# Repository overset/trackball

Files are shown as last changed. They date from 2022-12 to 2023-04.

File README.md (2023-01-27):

## Trackball Mezzanine PCBs

These are the mezzanine PCBs that connect the <a href="https://www.adafruit.com/product/4600">Adafruit QT Py</a> (SAMD21) MCU, <a href="https://github.com/mrjohnk/PMW3389DM">MrJohnK PMW3389</a> optical sensor breakout (<a href="https://www.tindie.com/products/jkicklighter/pmw3389-motion-sensor/">available on Tindie as of 2022</a>), simple components for the haptic feedback motor and pads for capacitive pickup wiring. This PCB allows for easy mounting inside the case for most components as well as a ground plane to help with the capacitive pickup interference. These are simple 2-layer PCBs that made with KiCad6 and includes a few custom footprints/symbols for the haptic motor. These can easily be fabricated through OSHPark, JLCPCB, etc. Original prototypes were fabricated by OSHPark and the gerber & hole files were exported from KiCad6 with OSHPark guidelines.

### Dual Optical Sensor PCB

*Currently work in progress*

This mezzanine PCB supports 2 optical sensor breakout boards being tested on a new case design. This leverages the PMW3389DM-T3QU or PMW3360DM-T2QU breakout boards from MrJohnK. Having the second optical sensor enables detecting horizontal ball movement (like a flat spin) to enable scroll/wheel events. This is specifically designed to work with the current case design detecting movements off a radial ball bearing for 1 sensor (scroll) and the trackball itself (x, y cursor movement).

<p align="center">
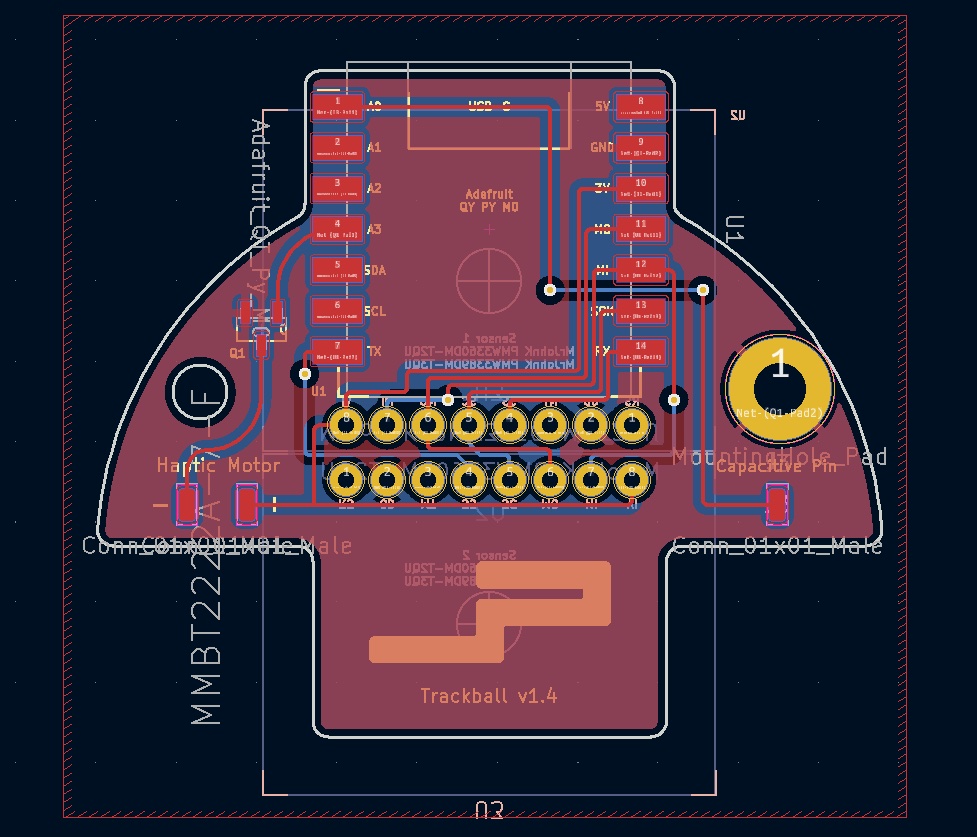
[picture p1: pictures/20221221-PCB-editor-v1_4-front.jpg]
	<span align="left"></span>
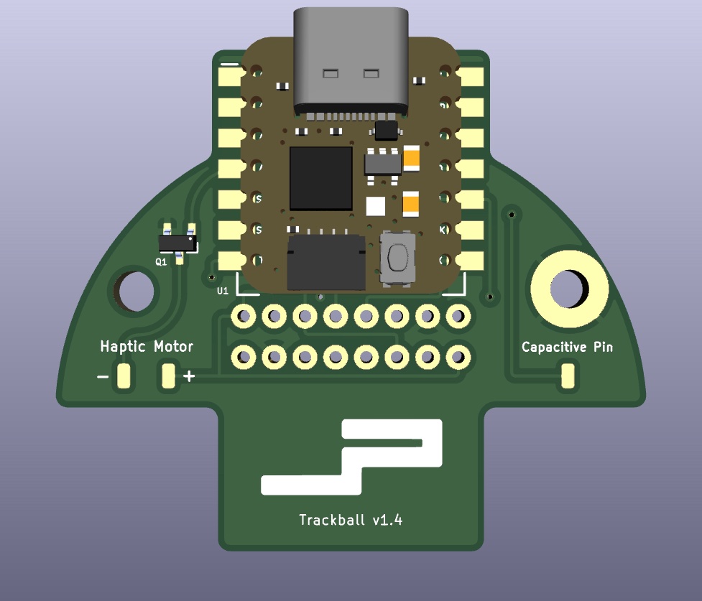
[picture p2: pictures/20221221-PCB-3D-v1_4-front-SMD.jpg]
	<span align="left"></span>
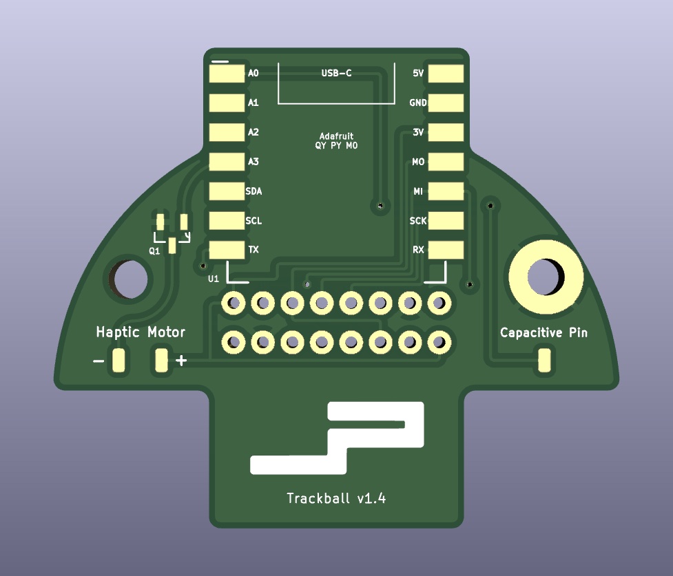
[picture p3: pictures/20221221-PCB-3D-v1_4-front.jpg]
	<span align="left"></span>
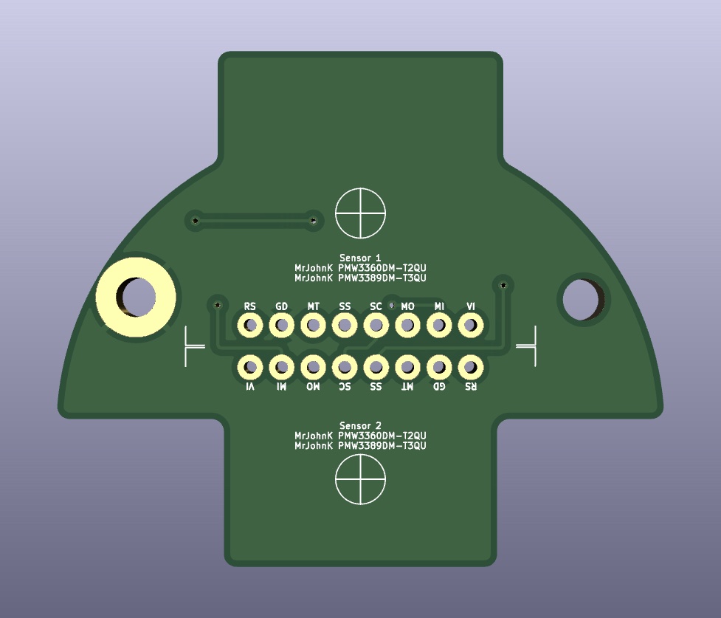
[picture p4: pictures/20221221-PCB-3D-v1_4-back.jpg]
	<span align="right"></span>
</p>

<p align="center">
	
</p>

### Single Optical Sensor PCB

This mezzanine PCB supports a single optical sensor breakout and is good for a dedicated trackball or dedicated scrollball. This allows for a smaller case design, but made with using a 50mm or larger ball.

<p align="center">
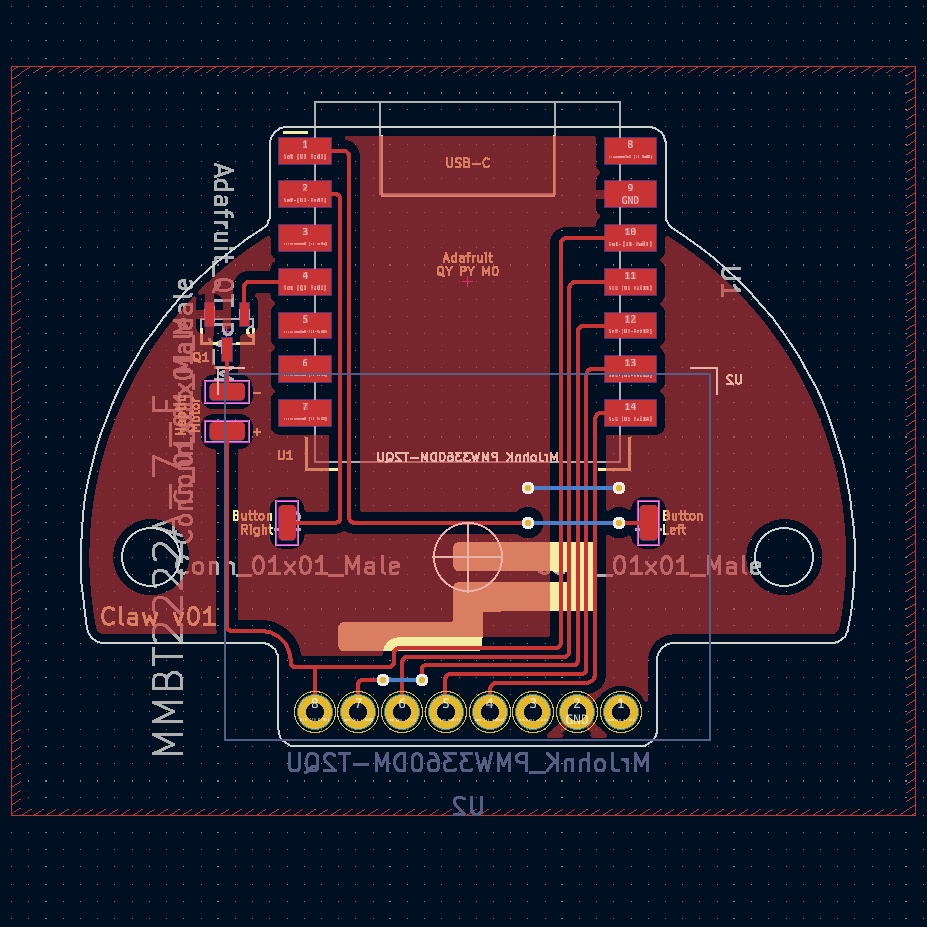
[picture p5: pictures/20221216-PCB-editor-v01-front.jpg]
	<span align="left"></span>
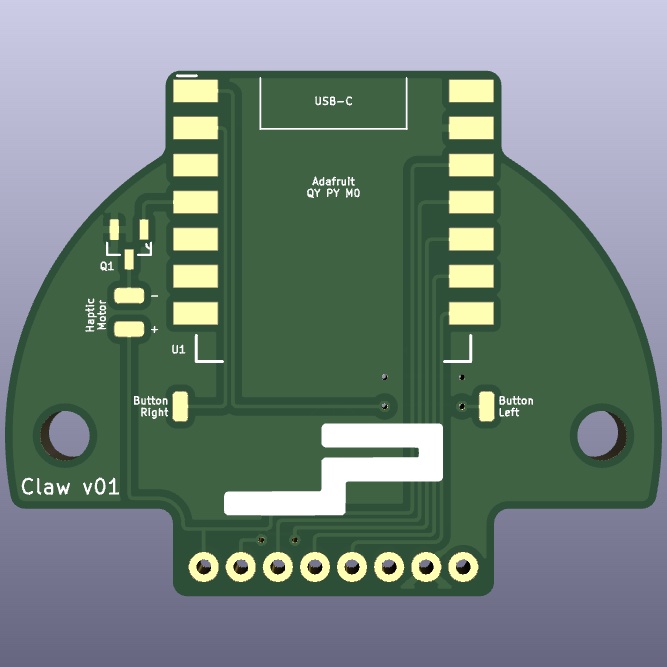
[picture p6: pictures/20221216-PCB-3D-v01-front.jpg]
	<span align="left"></span>
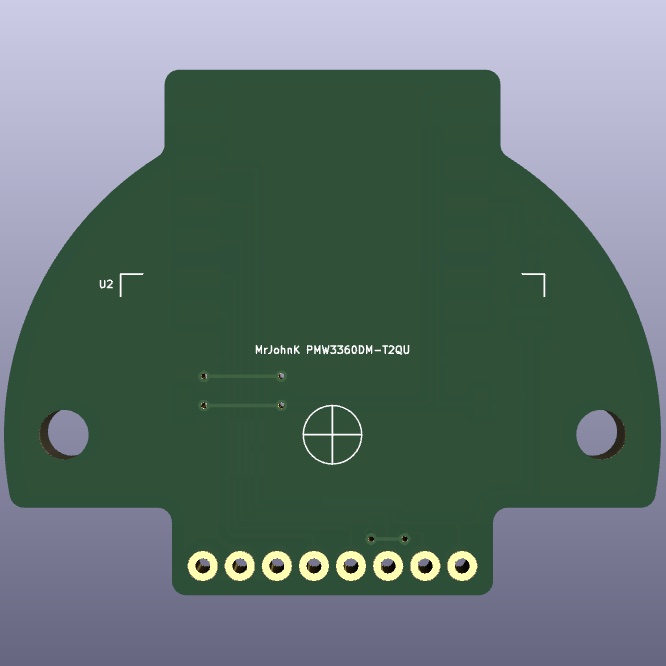
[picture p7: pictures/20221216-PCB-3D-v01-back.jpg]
	<span align="right"></span>
</p>

Assembly of the first print:

<p align="center">
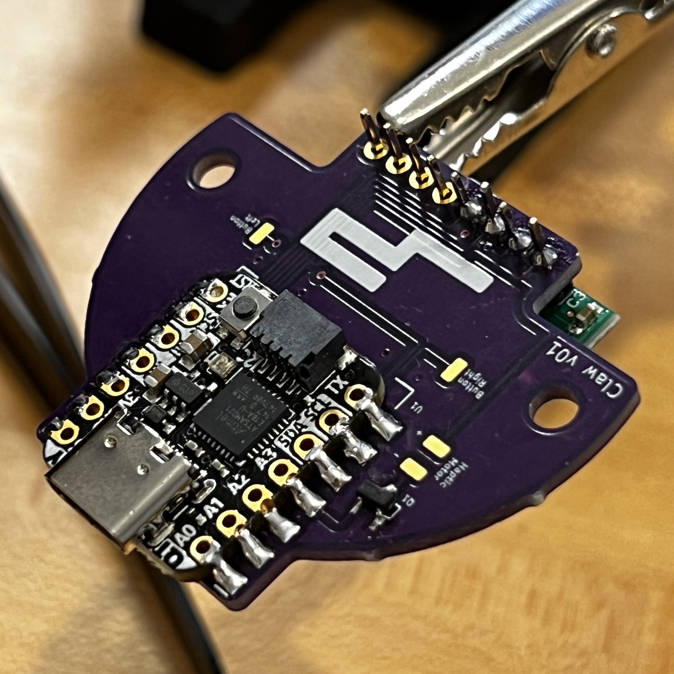
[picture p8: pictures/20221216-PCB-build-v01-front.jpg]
	<span align="left"></span>
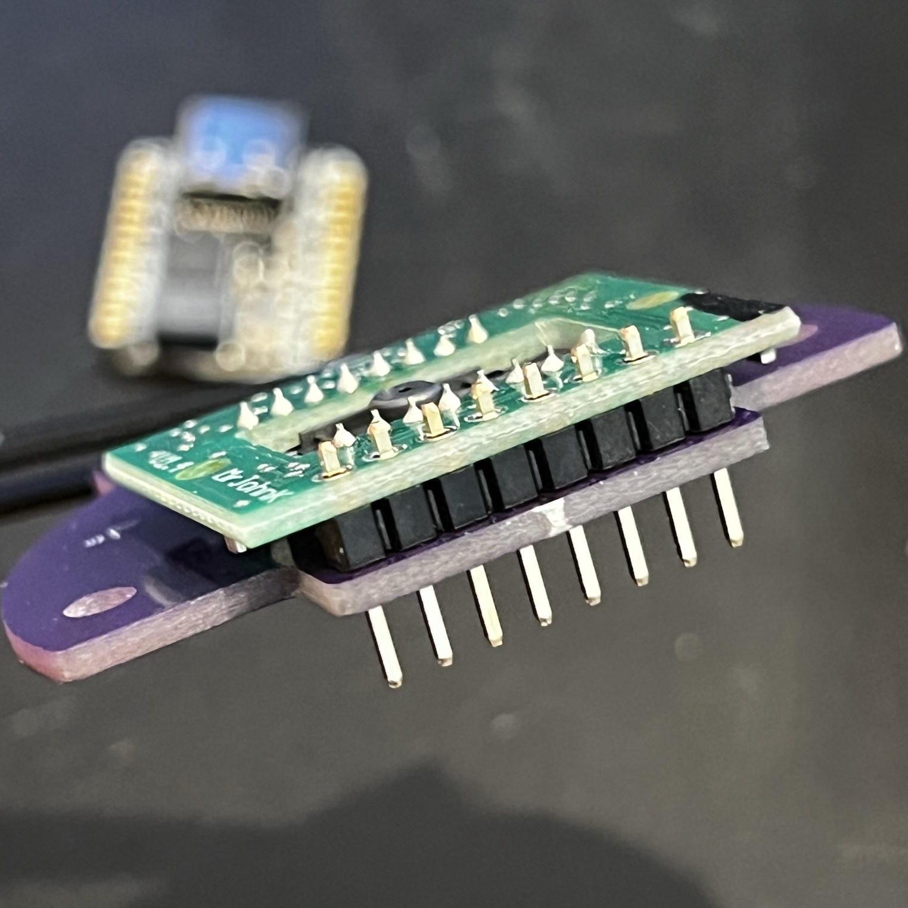
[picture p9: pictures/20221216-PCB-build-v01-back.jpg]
	<span align="left"></span>
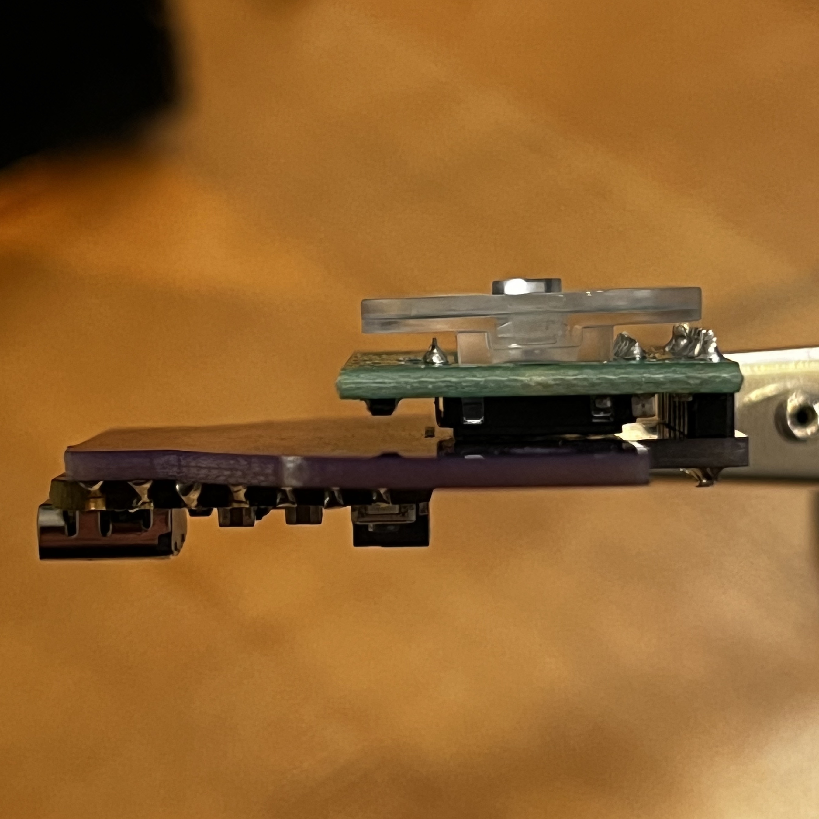
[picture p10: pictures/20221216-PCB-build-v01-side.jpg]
	<span align="right"></span>
</p>

## Credits, Attribution and Inspiration

* <a href="https://github.com/monroewilliams/trackball">MonroeWilliams' Trackball</a> project
* <a href="https://github.com/jfedor2">jfedor2's multiple trackball</a> projects

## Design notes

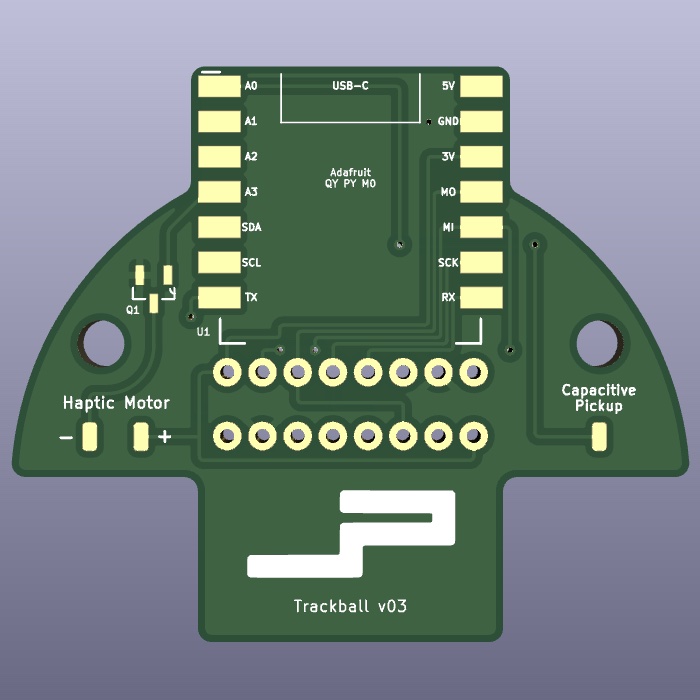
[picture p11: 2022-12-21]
pictures/20221221-PCB-3D-v03-front.jpg

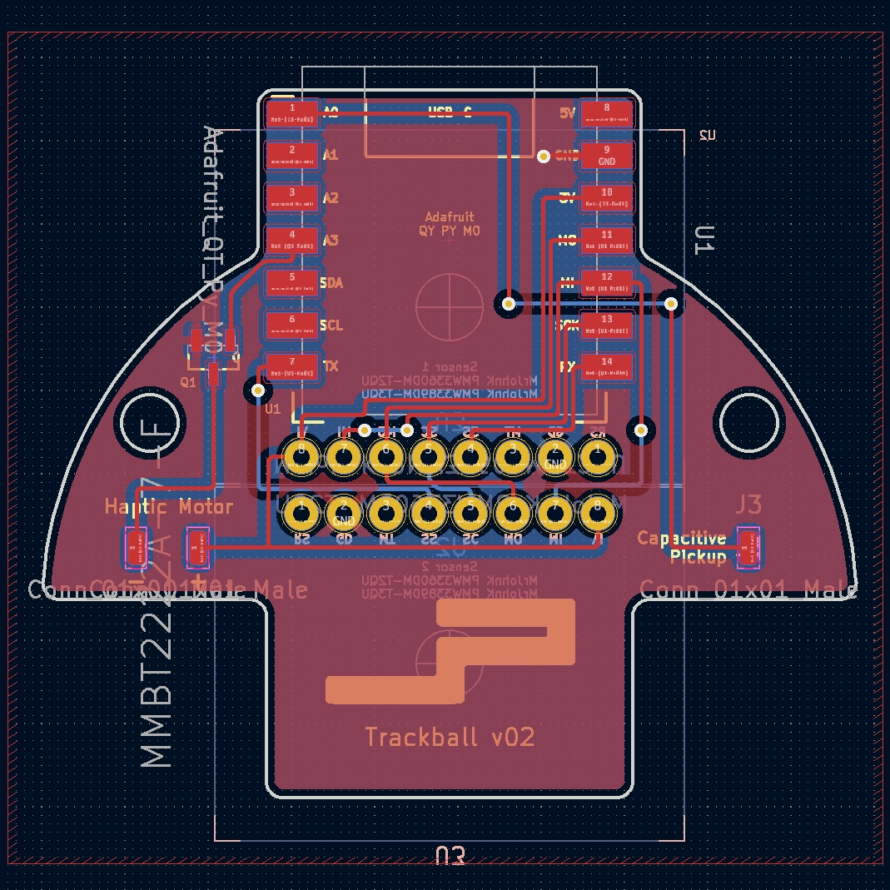
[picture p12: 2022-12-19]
pictures/20221218-PCB-editor-v02-front.jpg

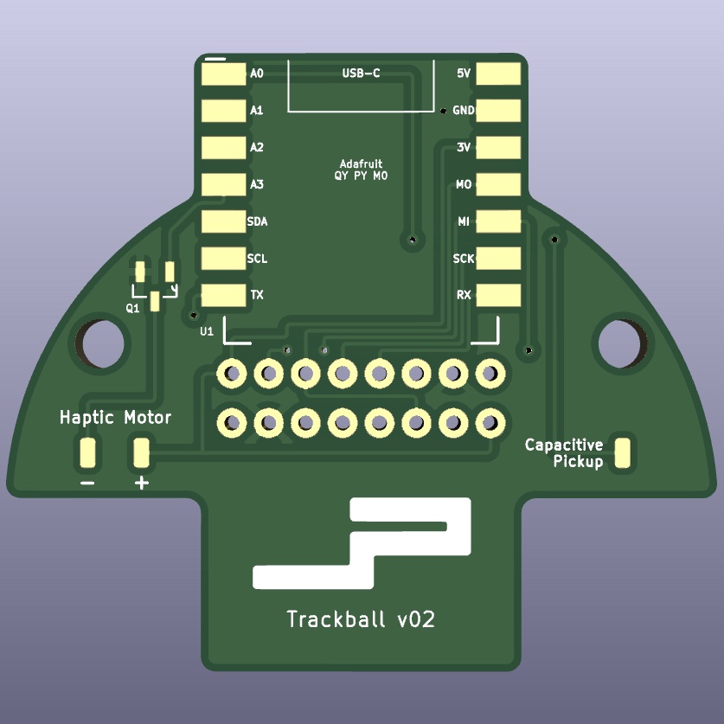
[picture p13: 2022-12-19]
pictures/20221218-PCB-3D-v02-front.jpg

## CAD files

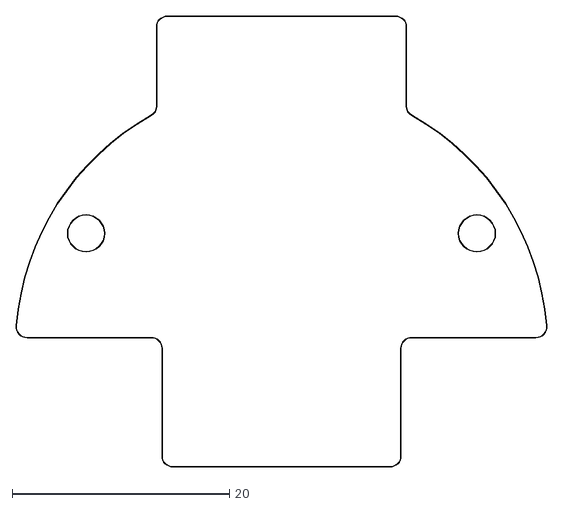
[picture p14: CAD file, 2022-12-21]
PCB-dual/PCB-dual-sensor-edge-cut-v03.dxf
48.9 x 41.5

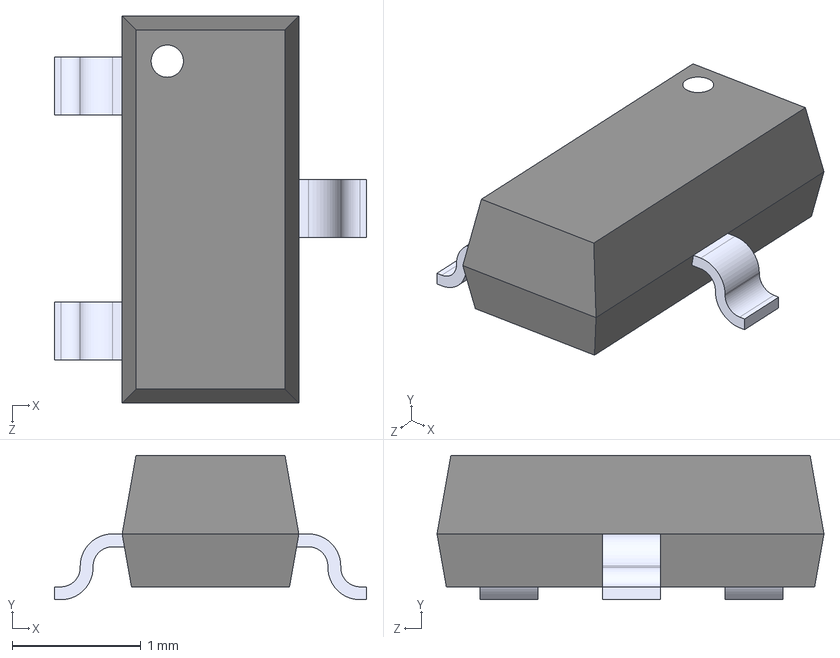
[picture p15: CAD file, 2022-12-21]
PCB-dual/MMBT2222A-7-F.step
2.42 x 1.12 x 3.00 mm

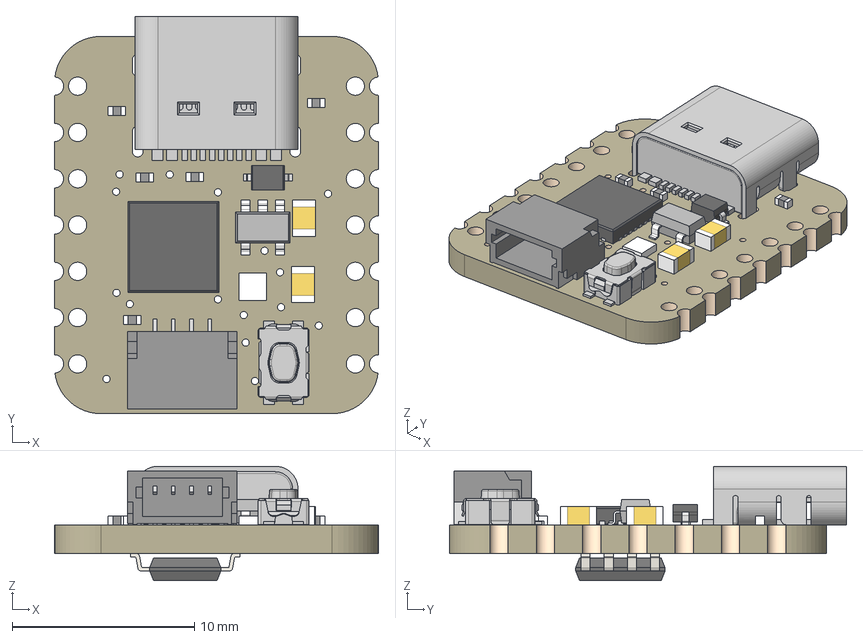
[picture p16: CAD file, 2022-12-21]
PCB-dual/4600 QTPy.step
17.8 x 21.8 x 6.28 mm
Board
10uF x 2
reset
ATSAMD21E
TPB1,27
5.1K x 5
USB TYPE C
STEMMA_I2C_QTSKINNY
AP2112K-3.3
WS2812B_SK6805_1515
NSR0320
SOIC8_150MIL

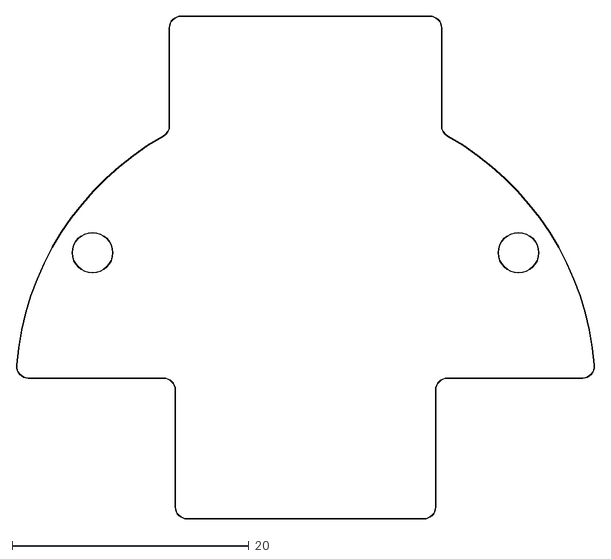
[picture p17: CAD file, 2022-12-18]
PCB-dual/dual sensor pcb edge cut.dxf
48.9 x 42.5

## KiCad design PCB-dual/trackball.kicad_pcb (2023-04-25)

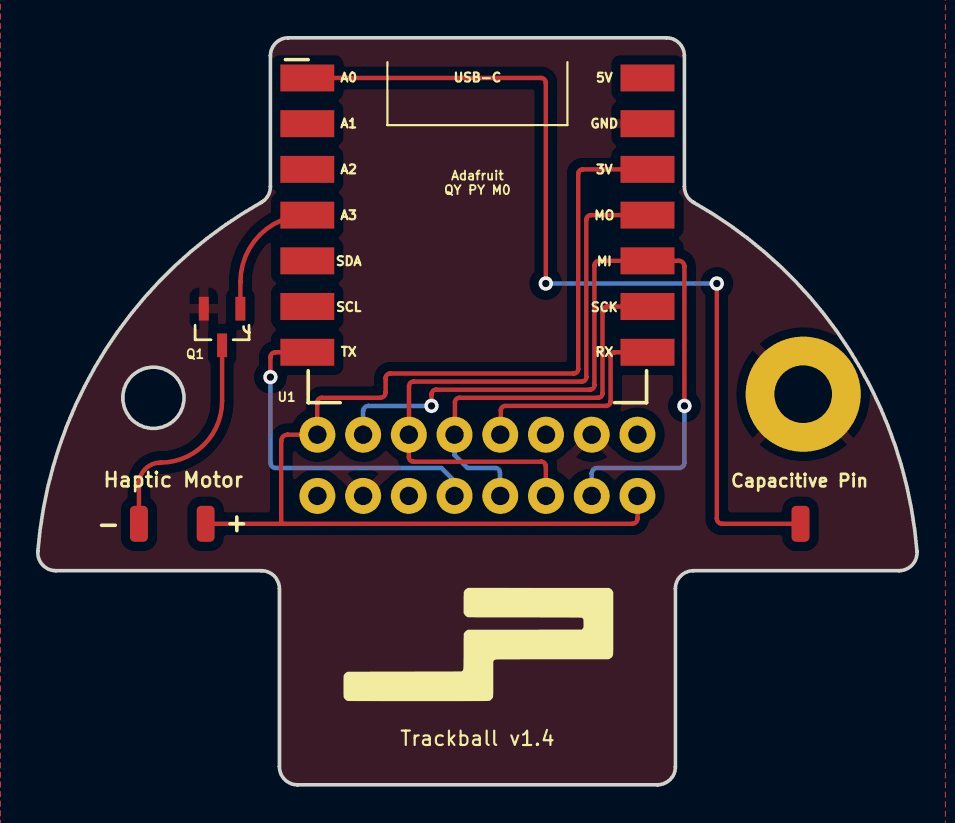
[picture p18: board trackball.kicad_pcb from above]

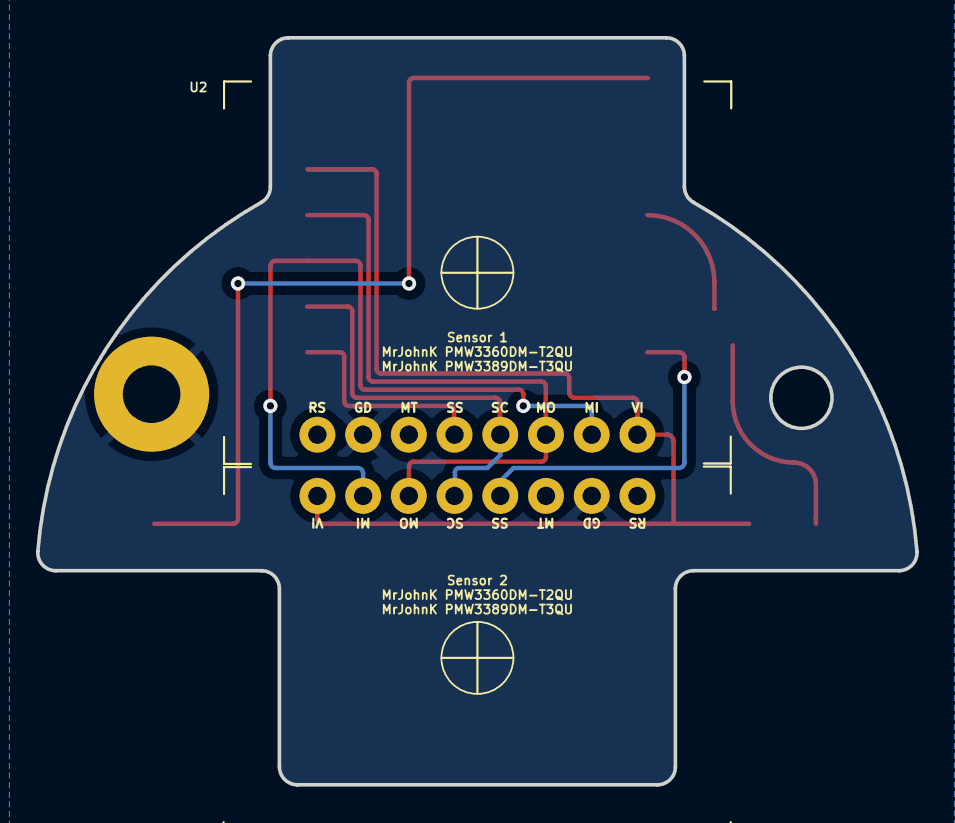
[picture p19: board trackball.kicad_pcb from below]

Board: 2 copper layers, 48.8 x 41.5 mm, 8 parts (2 on the bottom side), 10 nets.

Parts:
+: Conn_01x01_Male; SolderWirePad_1x01_SMD_1x2mm
-: Conn_01x01_Male; SolderWirePad_1x01_SMD_1x2mm
H1: MountingHole_Pad; MountingHole_3.2mm_M3_Pad
J3: Conn_01x01_Male; SolderWirePad_1x01_SMD_1x2mm
Q1: MMBT2222A-7-F
U1: Adafruit_QT_Py_M0; Adafruit_QT_PY_M0
U2, U3: MrJohnK_PMW3360DM-T2QU

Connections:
unnamed: +.1, U1.10 (3V), U2.8 (VI), U3.8 (VI)
unnamed: -.1, Q1.3 (C)
unnamed: J3.1, U1.1 (A0)
unnamed: Q1.1 (B), U1.4 (A3)
unnamed: H1.1, Q1.2 (E), U1.9 (GND), U2.2 (GD), U3.2 (GD)
unnamed: U1.7 (TX), U3.4 (SS)
unnamed: U1.11 (MO), U2.6 (MO), U3.6 (MO)
unnamed: U1.12 (MI), U2.7 (MI), U3.7 (MI)
unnamed: U1.13 (SCK), U2.5 (SC), U3.5 (SC)
unnamed: U1.14 (RX), U2.4 (SS)

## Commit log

2022-12-16 feat: added initial v01 KiCad6 project files and first pictures of mezzanine PCB
    [trackball-B_Cu.gbr, trackball-B_Mask.gbr, trackball-B_Silkscreen.gbr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]
2022-12-16 feat: added v01 build pictures with mezzanine PCB, QT Py and PMW3389 breakout
2022-12-16 bug: capacitive pickup, not haptic pickup
2022-12-17 docs: added links to breakouts, attributions and dual vs single PCB outline
2022-12-17 feat: move PCB to PCB-single to differentiate single vs dual sensor PCBs
    [trackball-B_Cu.gbr, trackball-B_Mask.gbr, trackball-B_Silkscreen.gbr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]
2022-12-17 docs: add more details for included gerbers and OSHPark preferences
2022-12-18 feat: add WIP for dual sensor PCB. Edge cut works with current 3D model geometry, footprints updated with more silkscreen adds. Just about to begin re-wiring the pads.
    [dual sensor pcb edge cut.dxf, trackball.kicad_pcb, trackball.kicad_sch]
2022-12-18 feat: first draft of v02 trackball with dual sensor support, fixes to footprints and OSHPark gerber .zip not yet tested
    [trackball-B_Cu.gbr, trackball-B_Mask.gbr, trackball-B_Silkscreen.gbr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]
2022-12-18 docs: quick intro with images for the draft dual sensor mezzanine PCB
2022-12-19 docs: typos on breakout boards sensor IDs
2022-12-19 feat: cleaned up tracks minimizing crossover on F/B layers, simplified some tracks, ground plane now on both sides
    [trackball-B_Cu.gbr, trackball-B_Mask.gbr, trackball-B_Silkscreen.gbr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]
2022-12-19 docs: updated v02 PCB editor view and 3D front/back images
2022-12-19 docs: dual sensor to the top of the list
2022-12-19 docs: cleaner markdown+html grid and renamed dual sensor pictures to correct timestamp
2022-12-21 feat: added 3D models for QT Py and diode to existing project footprints
    [trackball.kicad_pcb]
2022-12-21 bug: add .step files for updated footprints
    [4600 QTPy.step, MMBT2222A-7-F.step]
2022-12-21 feat: new v03 with new mounting hole placement and proper placement of second sensor with fitment in 55mm sphere sized case
    [PCB-dual-sensor-edge-cut-v03.dxf, trackball.kicad_pcb]
2022-12-21 feat: tweak to silkscreen
    [trackball.kicad_pcb]
2022-12-21 docs: added v03 dual sensor docs, step file from KiCad6
2022-12-21 feat: new gerbers for v03 of dual sensor PCB
    [trackball-B_Cu.gbr, trackball-B_Mask.gbr, trackball-B_Silkscreen.gbr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]
2022-12-21 feat: v03 dual sensor PCB OSHPark gerber .zip
2023-01-01 feat: v1.4 with ~3.4mm spacing between sensor header pins on center with new case optimization, QTPy positioning fix, new ground pad for grounding to case, few track tweaks
    [trackball.kicad_pcb, trackball.kicad_sch]
2023-01-01 feat: v1.4 gerbers and drill files for OSHPark
    [trackball-B_Cu.gbr, trackball-B_Mask.gbr, trackball-B_Silkscreen.gbr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]
2023-01-01 feat: v1.4 OSHPark gerber + drill zip
2023-01-27 docs: add quick video on reflow soldering SMD parts (QT Py and transistor) onto the v1.4 dual sensor PCB
2023-01-27 docs: add new v1.4 dual sensor PCB KiCAD images
2023-01-27 docs: fix v1.4 PCB editor picture to be same aspect ratio as 3D view
2023-04-25 feat: updated PCB to KiCad 7
    [trackball.kicad_pcb]

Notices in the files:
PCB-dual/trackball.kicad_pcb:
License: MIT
